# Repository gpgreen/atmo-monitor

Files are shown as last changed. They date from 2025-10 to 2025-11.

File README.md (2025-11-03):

# atmo-monitor

KiCad design for a atmospheric measurement board. The MCU is a
stm32f103cbt6. There are 2 main sensors. One is the PMS2007, which
measures particulates, ie PM2.5. The other sensor is a BME680, which
measures temperature, pressure, and organic compounds. The
measurements are output on an E-Ink tri-color display.

This design is a continuation of a project that I did using a nucleo dev board
and a perfboard pcb. The main goals used for this design:

    - Use smd devices that I had already for the project, instead of a dev board
    - Use an [Adafruit power supply breakout](https://www.adafruit.com/product/1944) that allows the use of a lithium battery. I didn't
    want to implement this on the PCB for this project, and I don't have those types of devices on hand.
    - Hand soldering for the pcb instead of my usual hot-plate reflow technique. This means
    using 1206 size components instead of 0603, and SO footprint parts. This also helps with
    the previous goal of using parts I had already, as my newer designs use TQFP footprints. I have successfully
    hand soldered the smaller parts, but it is very tedious.

I was able to finish the design using those goals and the only part I needed to purchase was the adafruit power breakout. It
is a 2-layer PCB that I have shared at [Oshpark](https://oshpark.com/shared_projects/oVsTK2Hw).

## Changes

- Rev A
  Original

## Firmware

[Firmware](https://github.com/gpgreen/atmo-monitor-stm32)

## Connections to Segger JTAG

I have put test points on the board, so that pogo pins can be used to program
the MCU.

[jlink web page](https://www.segger.com/products/debug-probes/j-link/technology/interface-description/)
```
**** 20 Pin connector for JTAG
                -------
    VTref      1|*   *|2 NC
    nTRST      3|*   *|4 GND
    TDI        5|*   *|6 GND
    TMS        7|*   *|8 GND
    TCK        9|*   *|10 GND
    RTCK      11|*   *|12 GND
    TDO       13|*   *|14 GND
    RESET     15|*   *|16 GND*
    DBGRQ     17|*   *|18 GND*
    5V Supply 19|*   *|20 GND*
                -------
```
From a 20pin JTAG connector, run wires to the following test pads to connect a debugger:
```
VTRef 1  <-> 3V3
SWDIO 7  <-> SWD
SWCLK 9  <-> SWC
RESET 15 <-> RST
GND   4  <-> GND
```

## Running SEGGER JLink

Run the JLink GDB server via the following:
```
JLinkGDBServer -if SWD -device STM32F103CB
```

GDB can be connected via the following:
```
gdb-multiarch --command=jlink-stm32.gdb target/thumbv7m/debug/main
```

## Running ocd
```
openocd -f interface/stlink-v3.cfg -f target/stm32f1x.cfg
```

## Credits

as always, thanks for the good work
- [Adafruit](https://www.adafruit.com)

## License

Licensed under

- MIT license ([LICENSE-MIT](LICENSE-MIT) or http://opensource.org/licenses/MIT)

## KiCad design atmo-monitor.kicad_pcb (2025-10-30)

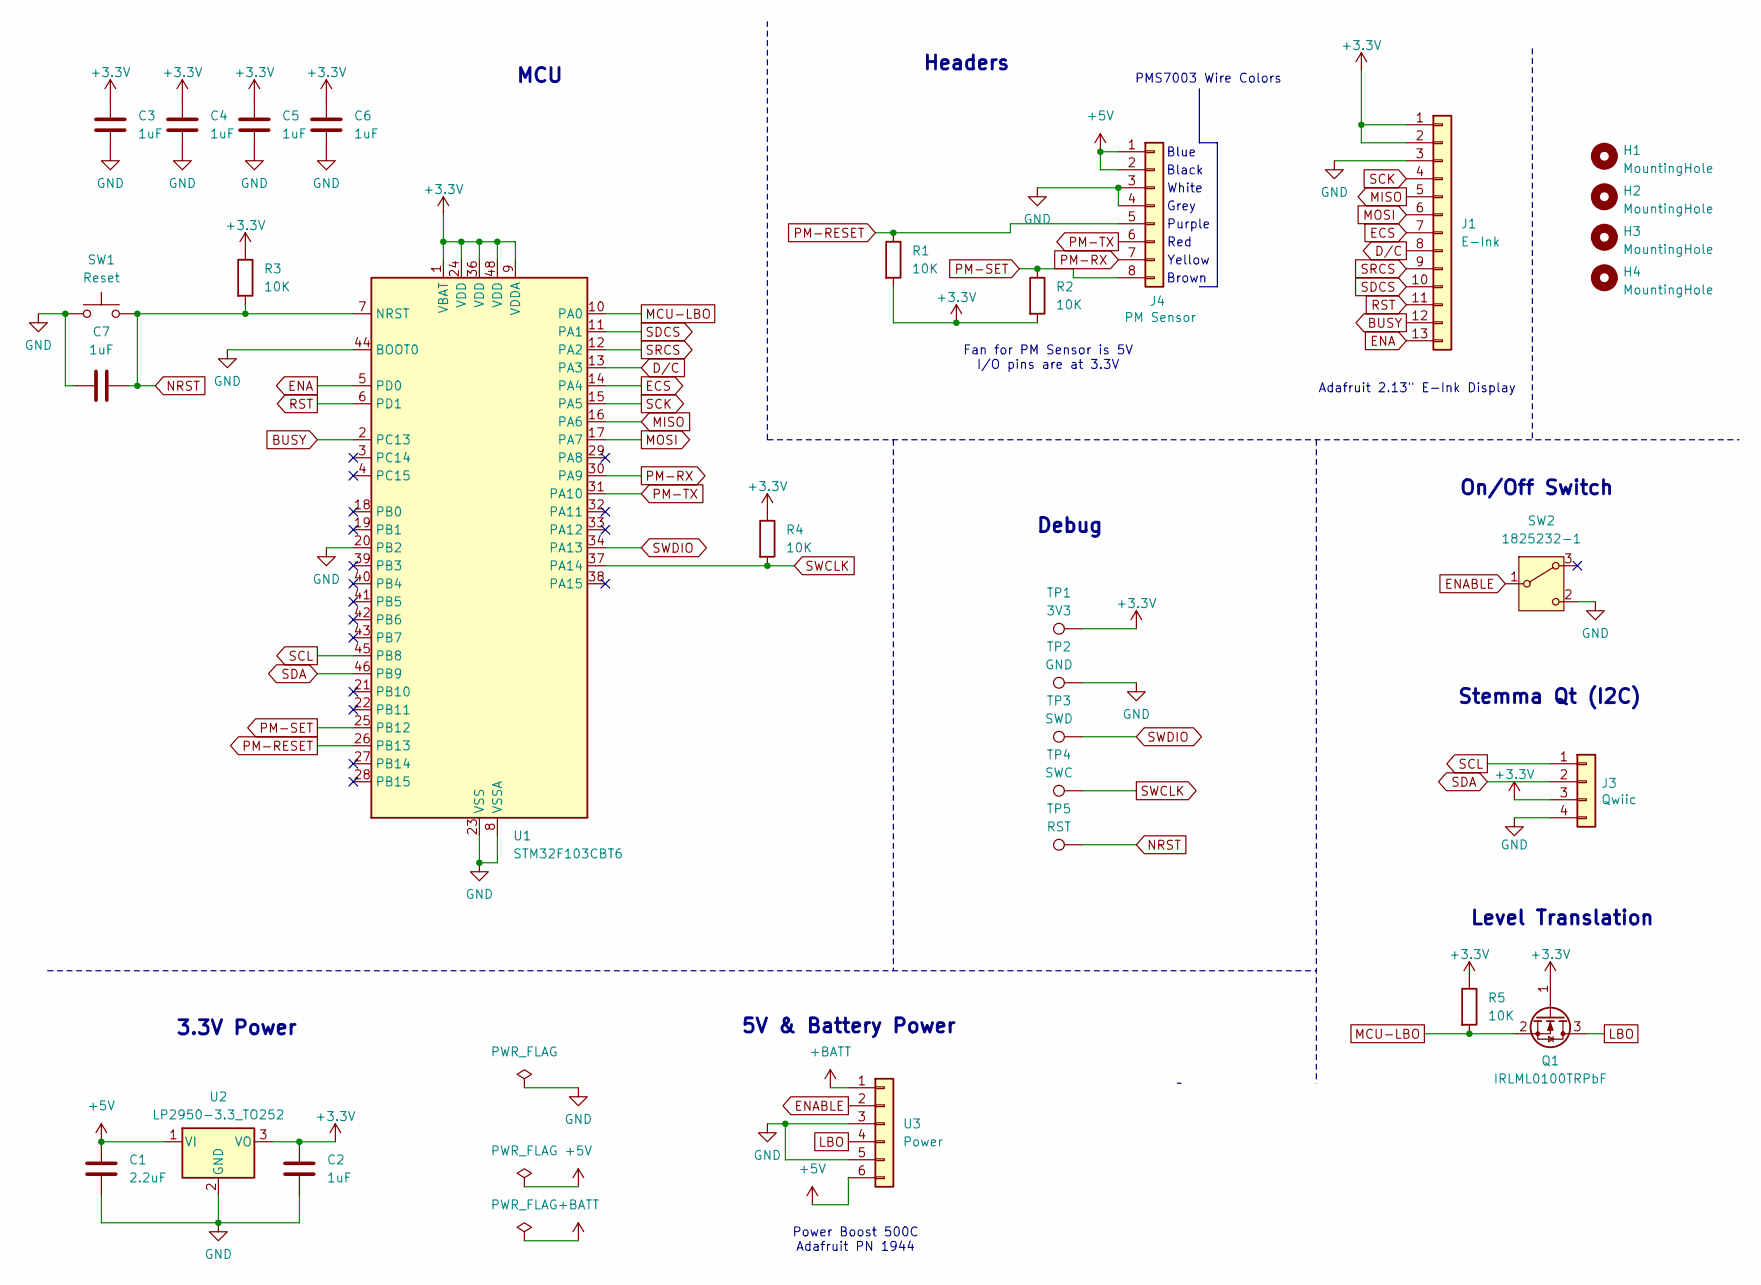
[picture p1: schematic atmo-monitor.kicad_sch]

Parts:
C1: 2.2uF; C_1206_3216Metric_Pad1.33x1.80mm_HandSolder
C2, C3, C4, C5, C6, C7: 1uF; C_1206_3216Metric_Pad1.33x1.80mm_HandSolder
H1, H2, H3, H4: MountingHole; MountingHole_2.5mm_Pad
J1: E-Ink; PinHeader_1x13_P2.54mm_Vertical
J3: Qwiic; JST_SH_BM04B-SRSS-TB_1x04-1MP_P1.00mm_Vertical
J4: PM Sensor; JST_PH_B8B-PH-K_1x08_P2.00mm_Vertical
Q1: IRLML0100TRPbF; SOT-23
R1, R2, R3, R4, R5: 10K; R_1206_3216Metric_Pad1.30x1.75mm_HandSolder
SW1: Reset; OnShine KPT-1187B
SW2: 1825232-1; TE-1825232-1
TP1: 3V3; TestPoint_Pad_D2.0mm
TP2: GND; TestPoint_Pad_D2.0mm
TP3: SWD; TestPoint_Pad_D2.0mm
TP4: SWC; TestPoint_Pad_D2.0mm
TP5: RST; TestPoint_Pad_D2.0mm
U1: STM32F103CBT6; LQFP-48_7x7mm_P0.5mm
U2: LP2950-3.3_TO252; TO-252-2
U3: Power; Adafruit Powerboost 500+

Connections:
+3.3V: C2.1, C3.1, C4.1, C5.1, C6.1, J1.1, J1.2, J3.3, Q1.1 (G), R1.2, R2.2, R3.1, R4.1, R5.1, TP1.1, U1.1 (VBAT), U1.9 (VDDA), U1.24 (VDD), U1.36 (VDD), U1.48 (VDD), U2.3 (VO)
+5V: C1.1, J4.1, J4.2, U2.1 (VI), U3.6
+BATT: U3.1
BUSY: J1.12, U1.2 (PC13)
D/C: J1.8, U1.13 (PA3)
ECS: J1.7, U1.14 (PA4)
ENA: J1.13, U1.5 (PD0)
ENABLE: SW2.1 (B), U3.2
GND: C1.2, C2.2, C3.2, C4.2, C5.2, C6.2, C7.2, J1.3, J3.4, J4.3, J4.4, SW1.1, SW2.2 (C), TP2.1, U1.8 (VSSA), U1.20 (PB2), U1.23 (VSS), U1.35 (VSS), U1.44 (BOOT0), U1.47 (VSS), U2.2 (GND), U3.3, U3.5
LBO: Q1.3 (D), U3.4
MCU-LBO: Q1.2 (S), R5.2, U1.10 (PA0)
MISO: J1.5, U1.16 (PA6)
MOSI: J1.6, U1.17 (PA7)
NRST: C7.1, R3.2, SW1.2, TP5.1, U1.7 (NRST)
PM-RESET: J4.5, R1.1, U1.26 (PB13)
PM-RX: J4.7, U1.30 (PA9)
PM-SET: J4.8, R2.1, U1.25 (PB12)
PM-TX: J4.6, U1.31 (PA10)
RST: J1.11, U1.6 (PD1)
SCK: J1.4, U1.15 (PA5)
SCL: J3.1, U1.45 (PB8)
SDA: J3.2, U1.46 (PB9)
SDCS: J1.10, U1.11 (PA1)
SRCS: J1.9, U1.12 (PA2)
SWCLK: R4.2, TP4.1, U1.37 (PA14)
SWDIO: TP3.1, U1.34 (PA13)

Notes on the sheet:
Black
3.3V Power
Headers
PMS7003 Wire Colors
Power Boost 500C Adafruit PN 1944
Debug
MCU
Grey
Red
Yellow
Adafruit 2.13" E-Ink Display
Purple
Level Translation
Fan for PM Sensor is 5V I/O pins are at 3.3V
White
Stemma Qt (I2C)
Blue
On/Off Switch
Brown
5V & Battery Power

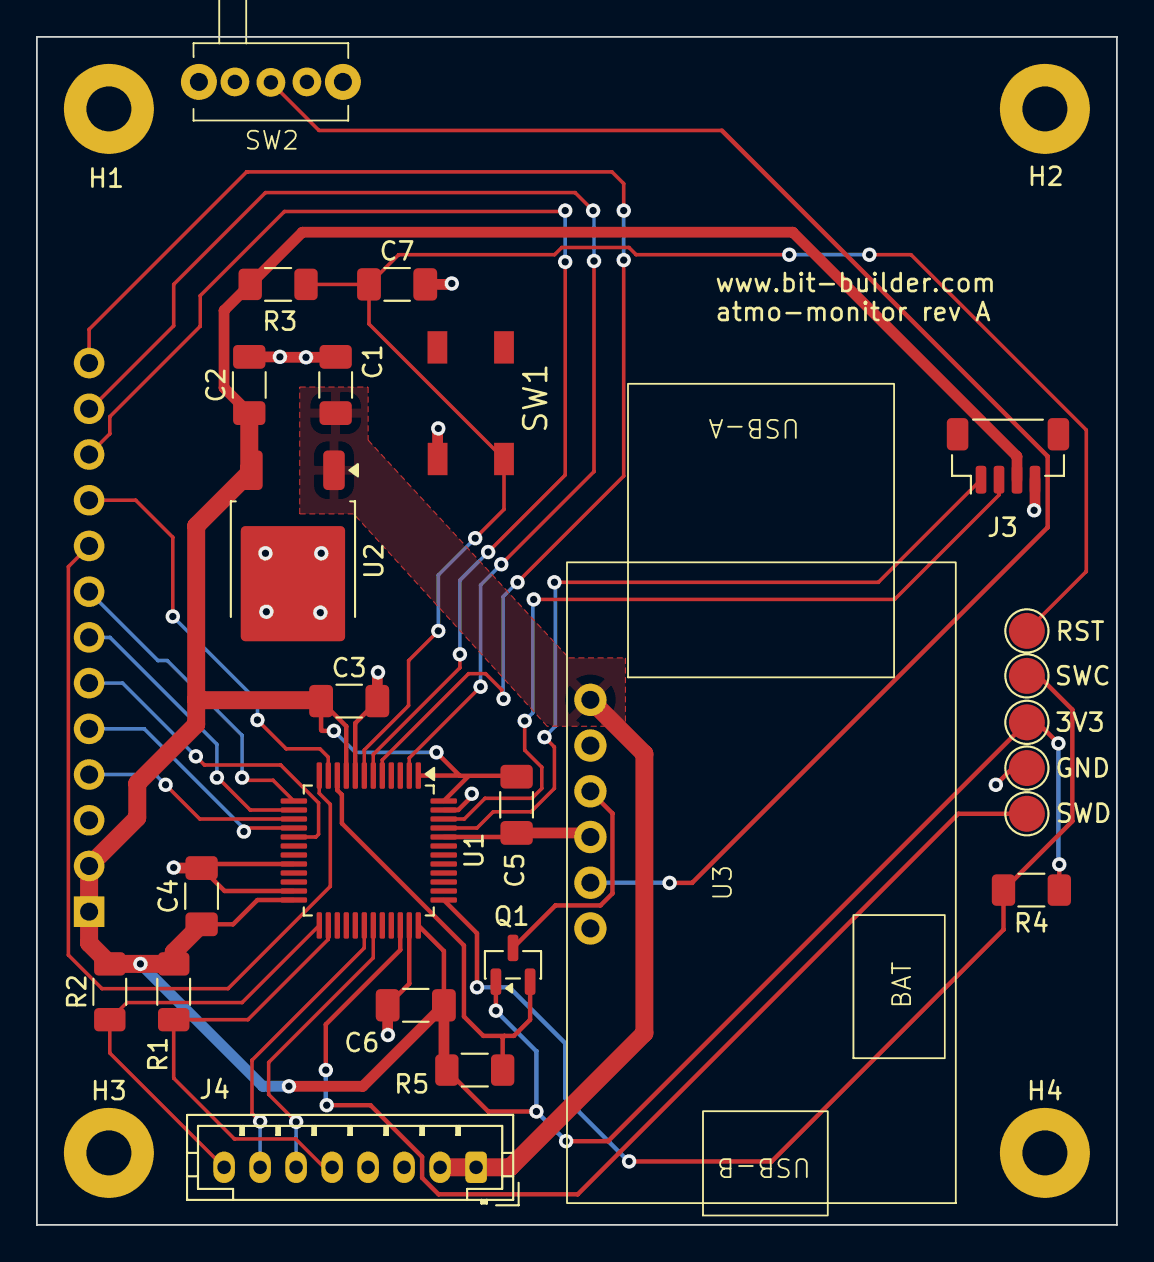
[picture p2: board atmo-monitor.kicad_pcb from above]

Board: 2 copper layers, 60.0 x 66.0 mm, 30 parts (1 on the bottom side), 25 nets.

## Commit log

2025-10-28 Finished initial design
    [atmo-monitor.kicad_pcb, atmo-monitor.kicad_sch]
2025-10-30 Moved 2 signals from output limited ports
    [atmo-monitor.kicad_pcb, atmo-monitor.kicad_sch]
2025-10-30 Added OshPark board link
    Updated readme a bit
2025-10-30 Added R4 for SWCLK
    Reordered debug test points
    Fixed schematic DRC problems
    [atmo-monitor.kicad_pcb, atmo-monitor.kicad_sch]
2025-10-30 Added R5 for LBO pull up on MCU
    For proper level translation, need R5
    Swapped RX and TX on PMS jumper so that it is legibly correct
    [atmo-monitor.kicad_pcb, atmo-monitor.kicad_sch]
2025-10-30 Updated trace routing for better clearance
    [atmo-monitor.kicad_pcb]
2025-10-30 Finished schematic drc checks
    Update pdb from schematic, no real changes
    [atmo-monitor.kicad_pcb, atmo-monitor.kicad_sch]
2025-10-30 Updated drawing blocks for rev A tagging
    [atmo-monitor.kicad_pcb, atmo-monitor.kicad_sch]
